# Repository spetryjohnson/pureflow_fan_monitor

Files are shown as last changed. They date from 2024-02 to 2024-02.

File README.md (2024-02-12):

# pureflow_fan_monitor

I have a couple of [PureFlow QT7 fanless fans](https://www.amazon.com/dp/B072PS3FR1?ref=ppx_yo2ov_dt_b_product_details&th=1) that I want to monitor and control through Home Assistant.

Specifically, I want Home Assistant to:

- Know if the fan is physically powered on or not
- Know the power level in use (0-9)
- Turn the fan on/off as part of automations 

I have solved this with a Raspberry Pi Zero W, a camera module, and an IR transmitter LED. 
 
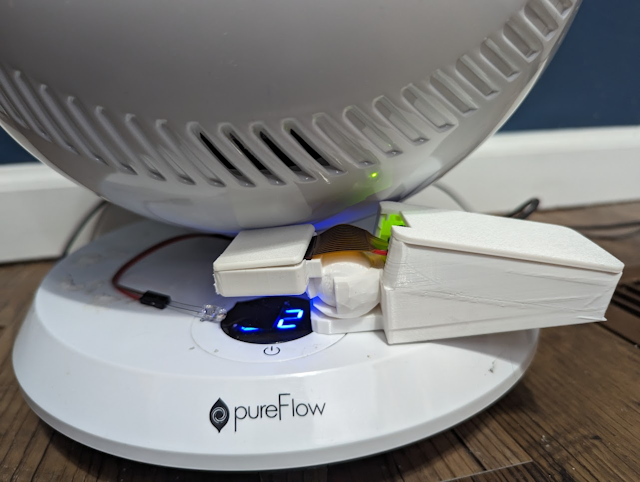
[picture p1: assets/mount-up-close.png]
Image of a PureFlow QT7 with my hackjob of a 3d printed case mounted to it


> [!WARNING]
> This works great for a Pi Zero W. The newer Pi Zero **2** W deprecates the legacy camera stack and requires a few changes to run. See the Pi Zero 2 section at the end of this page.

# Hardware setup

Required components:

- **Raspberry Pi Zero W** - the brains of the whole thing
- **Raspberry Pi camera** - for taking pictures of the fan's LCD
- **[IR LED](https://www.amazon.com/dp/B00M1PN5TK?psc=1&ref=ppx_yo2ov_dt_b_product_details)** - IR transmitter that sends commands to the fan
- **220 Ohm resistor** - limits LED current draw and protects the PI
- **BC-337 transistor** - allows LED to be switched on/off by a GPIO pin
- **3d printed enclosure** - (optional) for mounting to the base of the fan

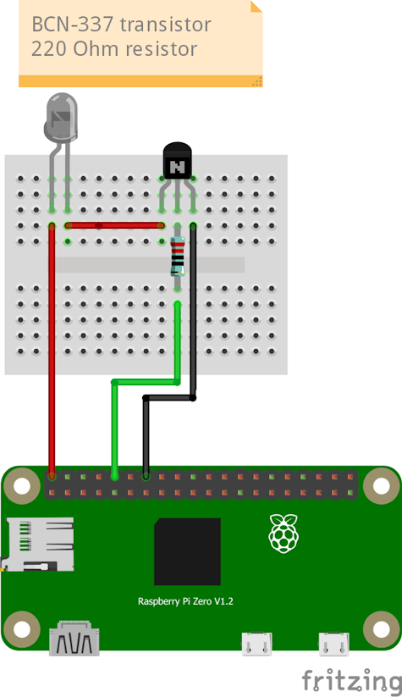
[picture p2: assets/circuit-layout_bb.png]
Fritzing image showing a circuit from 5V to LED to collector side of transistor, with resistor between base and GPIO 15


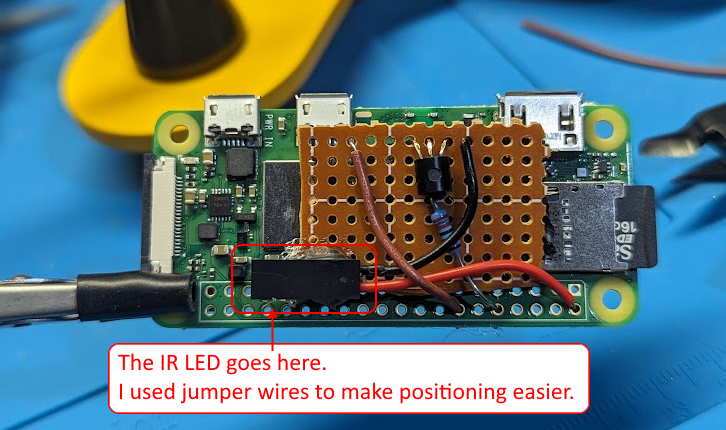
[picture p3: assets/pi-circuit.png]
Picture of the pi with the transistor and resitor soldered to it


> [!NOTE]
> Other transistors and resistors might work. I'm not a hardware guy, so follow my instructions at your own risk ;)

# Software installation

This system relies on two Python scripts that are installed as systemd services:

- **pureflow_OCR.service** - Monitors the fan's LCD screen and reports the current power level over MQTT
- **pureflow_webIR.service** - Web app that triggers IR transmissions in response to HTTP requests

## Get source code

Install the Github CLI and then pull down this repo (or use any other way to get these files onto your machine).

```
From https://github.com/cli/cli/blob/trunk/docs/install_linux.md

type -p curl >/dev/null || (sudo apt update && sudo apt install curl -y)
curl -fsSL https://cli.github.com/packages/githubcli-archive-keyring.gpg | sudo dd of=/usr/share/keyrings/githubcli-archive-keyring.gpg \
&& sudo chmod go+r /usr/share/keyrings/githubcli-archive-keyring.gpg \
&& echo "deb [arch=$(dpkg --print-architecture) signed-by=/usr/share/keyrings/githubcli-archive-keyring.gpg] https://cli.github.com/packages stable main" | sudo tee /etc/apt/sources.list.d/github-cli.list > /dev/null \
&& sudo apt update \
&& sudo apt install gh -y
```
```
gh repo clone spetryjohnson/pureflow_fan_monitor
```

## Create RAM disk for image manipulation (optional)

This involves a lot of reading and writing image files to disk. To reduce wear on the SD card, create a tmpfs RAM disk to hold them instead.

```
sudo mkdir /var/tempmem
sudo nano /etc/fstab

Add this line to fstab:
  -> tmpfs /var/tempmem tmpfs nodev,nosuid,size=400M 0 0

sudo mount -a
```

## Install ssocr

[ssocr](https://github.com/auerswal/ssocr) is a third party tool for doing OCR of "seven segment displays", e.g. the LCD that displays the power level.

```
sudo apt install ssocr -y
```

## Install ImageMagick

[ImageMagick](https://imagemagick.org/) is an open source image manipulation suite. It is required to run the Python module [Wand](https://pypi.org/project/Wand/)

```
sudo apt install imagemagick -y
```

## Install pigpio daemon

This is needed by the PiIR package for sending IR commands.

```
sudo apt install pigpio -y
sudo systemctl enable pigpiod
sudo systemctl start pigpiod
```

## Create virtual Python environment (optional) 

It's recommended to use a virtual environment, unless this is the only Python script running on the pi. Even then, it's good practice. (If you skip this step, you'll need to adjust paths in the service files accordingly)

```
python3 -m venv .venv
. .venv/bin/activate
```

## Install Python dependencies

```
pip install picamera Wand paho-mqtt Pillow flask gunicorn PiIR
```

- Camera, Wand, paho-mqtt, and Pillow are used for OCR
- Flask, gunicorn, and PiIR are used for the web app and IR control

## Create the system services

```
sudo cp displayOCR/pureflow_OCR.service /lib/systemd/system
sudo systemctl enable pureflow_OCR.service
sudo systemctl start pureflow_OCR.service

sudo cp webIR/pureflow_webIR.service /lib/systemd/system
sudo systemctl enable pureflow_webIR.service
sudo systemctl start pureflow_webIR.service
```

# Adding the monitor to the fan

> [!IMPORTANT]
> You will need to tweak the config file based on how you mount the camera to the fan.

## Placement

I place my monitors on the right hand side of the fans so that all of the cables can route behind the fan and be hidden from view.

You want the camera to be 90 degrees rotated with respect to the LCD display. Technically you should be able to use any orientation, since we rotate the image before processing it anyways, but in my testing I found *significant* performance degredation (at least on a pi zero w) when rotating by values other than exactly 90 degrees.

## Testing the camera

Access the web app at **http://<ip_or_host>:8080**. It will show you the current power reading, the image that last caused a *change* to the power reading, and the 10 most recent readings.

For each reading you'll see the raw image captured by the camera as well as the processed image that was used for OCR.  

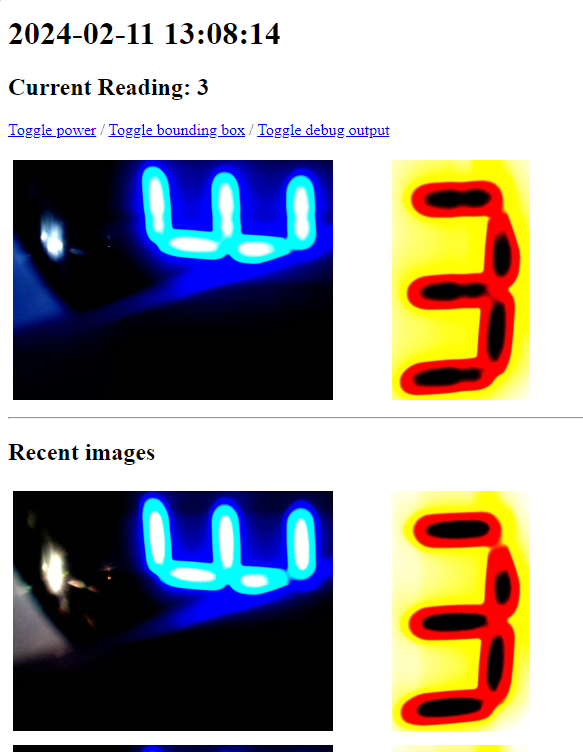
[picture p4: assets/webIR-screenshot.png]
Screenshot of the web app showing recent images and readings


> [!NOTE]
> If it isn't cropping the image correctly for your placement either adjust the camera so that it is, or adjust the cropping region defined in `config.ini`.

## Adjusting the cropped region

> [!NOTE]
> The fan supports speeds up to 12, but I only go up to 4 or 5. I designed this app to read the rightmost digit only.

In the web app, click the "toggle bounding box" link. This will begin adding a red box over the images showing the region that is being cropped and processed.

Load one of those images into an image editor and determine the X,Y coordinates that cleanly isolate the rightmost digit of the LCD display. 

Put those coordinates into `config.ini`

```
X,Y of top-left start and bottom-right end of the cropping region

CROP_STARTX = 250	
CROP_STARTY = 0 	
CROP_ENDX = 640
CROP_ENDY = 222
```

> [!IMPORTANT]
> Don't forget to disable the bounding box once you get it working, it adds unnecessary load.

# Setting up Home Assistant

The monitor will post power level changes to Home Assistant via MQTT. 

Home Assistant will use a Template Switch to monitor the state and to trigger IR commands to the fan when the switch is toggled.

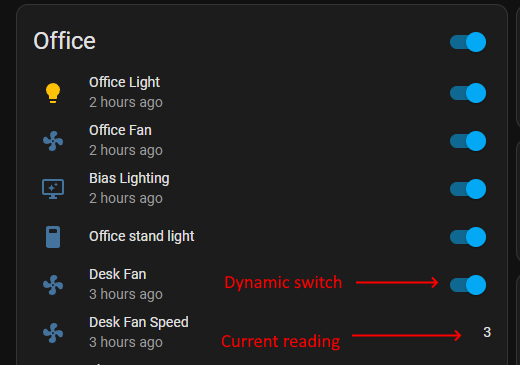
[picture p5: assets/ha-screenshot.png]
Screenshot of Home Assistant showing a template switch and the current power level in a dashboard


## MQTT setup

Edit `config.ini` and include your MQTT broker information.

```
SEND_MQTT = True
MQTT_HOST = your.mqtt.host
MQTT_TOPIC = home/rooms/office/deskfan/power
```

## MQTT sensor 

In Home Assistant, edit `configuration.yaml` and define a new sensor:

```
mqtt:
  sensor:
    - name: "Pureflow Fan Power Level"
      unique_id: "sensor_office_deskfan_power"
      state_topic: "home/rooms/office/deskfan/power"
      value_template: "{{ value_json.currentState }}"
      payload_available: "online"
      payload_not_available: "offline"
      json_attributes_topic: "home/rooms/office/deskfan"
      json_attributes_template: "{{ value_json | tojson }}"
```

## MQTT REST command

In Home Assistant, edit `configuration.yaml` and define a new REST command. This allows HA to make HTTP calls to the web service.

```
rest_command:
  pureflow_fan_toggle_power:
    url: "http://<ip_or_hostname_of_pi>:8080/toggle"
    method: GET
```

## Template switch

A Template Switch in Home Assistant will act as a power button. It uses the current power level to determine if the fan is "on" or "off" and calls the appropriate service to switch states.

```
switch:
  - platform: template
    switches:
      pureflow_fan_dynamic_switch:
        unique_id: "pureflow_fan_dynamic_switch"
        friendly_name: "Pureflow Fan Dynamic Switch"
        value_template: "{{ not states('sensor.pureflow_fan_power_level') in ['off', '0'] }}"
        turn_on:
          - condition: state
            entity_id: switch.pureflow_fan_dynamic_switch
            state: 'off'
          - service: rest_command.pureflow_fan_toggle_power
        turn_off:
          - condition: state
            entity_id: switch.pureflow_fan_dynamic_switch
            state: 'on'
          - service: rest_command.pureflow_fan_toggle_power
```

# Troubleshooting

## Manually sending the power toggle IR command

`piir play --gpio 15 --file webIR/pureflow-IR-commands.json power`

## Checking the logs of a running service

`sudo journalctl -f -u pureflow_OCR.service`

## Running the web server manually for testing

`flask run --host=0.0.0.0 --port 8080 --debug`

# Pi Zero 2 W support

There are major changes to the camera stack with the 2nd iteration of the Pi Zero. You will need to:

1. Disable the legacy camera support in `raspi-config`
1. Install [PiCamera2](https://github.com/raspberrypi/picamera2)
1. Create your Python virtual environment using `--system-site-packages` ([see this link](https://forums.raspberrypi.com/viewtopic.php?t=361758))

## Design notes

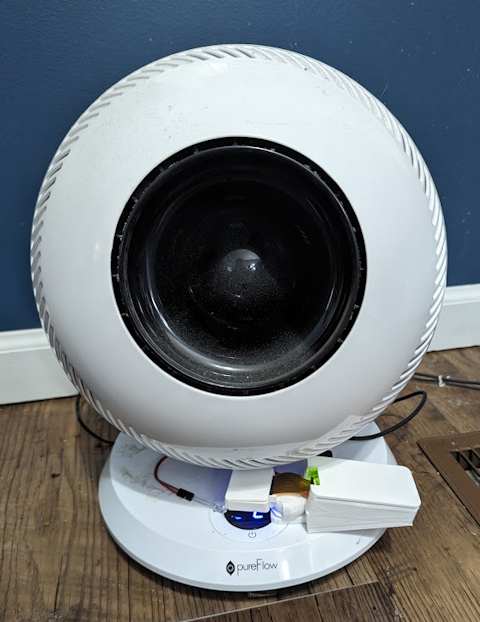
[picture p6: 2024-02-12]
assets/pureflow_fan.png

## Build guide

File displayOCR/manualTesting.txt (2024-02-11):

# take a picture with same settings used by the app
raspistill -w 640 -h 480 -n -co 85 -t 2000 -o test.jpg

# crop using imagemagick (equivalent to Wand in python)
# specific dimensions will need determined after camera is fixed in place
# format is ({length_of_cropped_area}x{height_of_cropped_area}+{xstart}+{ystart}
convert test.jpg -crop 393x222+180+0 test_cropped.jpg

# rotate
convert test_cropped.jpg -rotate 90 test_rotated.jpg

# negation makes ssocr more accurate
convert test_rotated.jpg -negate test_negated.jpg

# OCR
ssocr -d 1 test_negated.jpg

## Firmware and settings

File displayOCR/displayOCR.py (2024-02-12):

import os, sys, datetime, time, io 

# For handling the config file
from configparser import ConfigParser, ExtendedInterpolation

# For image generation and preparation
from shutil import copyfile
from picamera import PiCamera
from wand.image import Image
from PIL import Image as PilImage, ImageDraw as PilImageDraw

# For shelling out to ssocr
import subprocess

# For MQTT
import paho.mqtt.client as mqtt
import json

# For RCP communication
import _thread
from multiprocessing.connection import Listener
from multiprocessing import ProcessError as MultiprocProcessError

#--------------------------------------------------------
# Load config file
#
# (See config file for setting documentation)
#
# Some of these can be changed at runtime through RPC calls, others
# cannot. For simplicity everything is a mutable global.
#--------------------------------------------------------
config = ConfigParser(interpolation=ExtendedInterpolation())
config.read('../config.ini')

if (os.path.exists('../config.ini.local')):
	config.read('../config.ini.local')

CROP_STARTX = config['OCR'].getint('CROP_STARTX')
CROP_STARTY = config['OCR'].getint('CROP_STARTY')
CROP_ENDX = config['OCR'].getint('CROP_ENDX')
CROP_ENDY = config['OCR'].getint('CROP_ENDY')
SEND_MQTT = config['OCR'].getboolean('SEND_MQTT')
MQTT_HOST = config['OCR'].get('MQTT_HOST')
MQTT_TOPIC = config['OCR'].get('MQTT_TOPIC')
MAX_TIME_BETWEEN_MQTT_LOG_SEC = config['OCR'].getint('MAX_TIME_BETWEEN_MQTT_LOG_SEC')
ADD_CROP_BOX_TO_IMG = config['OCR'].getboolean('ADD_CROP_BOX_TO_IMG')
DEBUG = config['OCR'].getboolean('DEBUG')
STATIC_FILE_PATH = config['OCR'].get('STATIC_FILE_PATH')
LAST_CHANGE_ORIG_PATH = config['OCR'].get('LAST_CHANGE_ORIG_PATH')
LAST_CHANGE_PROC_PATH = config['OCR'].get('LAST_CHANGE_PROC_PATH')
LAST_CHANGE_TEXT_PATH = config['OCR'].get('LAST_CHANGE_TEXT_PATH')
LAST_ERROR_PATH = config['OCR'].get('LAST_ERROR_PATH')
MAX_IMAGES_TO_KEEP = config['OCR'].getint('MAX_IMAGES_TO_KEEP')
LOOP_DELAY_SEC = config['OCR'].getfloat('LOOP_DELAY_SEC')
USE_RPC = config['OCR'].getboolean('USE_RPC')
RPC_PORT = config['OCR'].getint('RPC_PORT')
RPC_SECRET = bytes(config['OCR'].get('RPC_SECRET', 'Super secret'), 'utf-8')

#--------------------------------------------------------
# Use a background thread to listen to commands from the web app 
#--------------------------------------------------------
def startListenerThread():
	global DEBUG, ADD_CROP_BOX_TO_IMG
	
	address = ('localhost', RPC_PORT)
	listener = Listener(address, authkey=RPC_SECRET)

	while True:
		if (DEBUG): print('[listener] Waiting for connection...')
		try:
			conn = listener.accept()
		except MultiprocProcessError:
			print('[listener] Error making connection. Could be invalid secret key from client')
			continue
		
		if (DEBUG): print ('[listener] Connection accepted from ', listener.last_accepted)

		if (DEBUG): print ('[listener] Waiting for message...')
		msg = conn.recv()
		if (DEBUG): print ('[listener] Received: ', msg)
		
		# Ugh I'm on python 3.9 which doesn't have switch case. 
		# What is this the 1700s?
		if (msg == 'toggleBoundingBox'):
			ADD_CROP_BOX_TO_IMG = not ADD_CROP_BOX_TO_IMG
		elif (msg == 'toggleDebug'):
			DEBUG = not DEBUG
		else:
			print('[listener] Unrecognized command: ', msg)
			
		if (DEBUG): print('[listener] Closing connection')
		conn.close()
	
	if (DEBUG): print('[listener] Closing listener')
	listener.close()

#--------------------------------------------------------
# Main program
#--------------------------------------------------------
if __name__ == '__main__':
	# local vars
	if (SEND_MQTT):
		mqttClient = mqtt.Client()
	
	imageCounter = 0			# For rotating image names
	valueOfLastChange = ''		# Value that last triggered a change in value
	timeOfLastChange = datetime.datetime.now()

	if (USE_RPC):
		print('Start background listener... ', end='', flush=True)
		_thread.start_new(startListenerThread, ())	
		print('Done!')

	print('Init camera....', end='', flush=True)
	with PiCamera() as camera:
		camera.resolution  = (640, 480)
		camera.contrast = 85
		time.sleep(2)
		print(' Ready!')

		# For each image we store the original image, the processed image,
		# and the OCR reading.

		while(True):
			now = datetime.datetime.now()	
			
			if (imageCounter >= MAX_IMAGES_TO_KEEP):
				imageCounter = 1
			else:
				imageCounter = imageCounter + 1

			pathPrefix = STATIC_FILE_PATH + 'reading-' + str(imageCounter)

			origImagePath = pathPrefix + '-orig.jpg'
			procImagePath = pathPrefix + '-processed.jpg'
			textReadingPath = pathPrefix + '-reading.txt'
			
			if (DEBUG): print('Getting image ' + origImagePath + '...', end='', flush=True)
			camera.capture(origImagePath)
			if (DEBUG): print('Done!')
			
			if (ADD_CROP_BOX_TO_IMG):
				if (DEBUG): print('Adding bounding box to ' + origImagePath + '... ', end='', flush=True)
				origImg = PilImage.open(origImagePath)
				draw = PilImageDraw.Draw(origImg)
				draw.rectangle((CROP_STARTX, CROP_STARTY, CROP_ENDX, CROP_ENDY), fill = None, outline="red")
				origImg.save(origImagePath, "JPEG")
				if (DEBUG): print('Done!')
			
			if (DEBUG): print('Processing image ' + procImagePath + '... ', end='', flush=True)
			with Image(filename = origImagePath) as image:
				with image.clone() as clone:
					clone.crop(CROP_STARTX, CROP_STARTY, CROP_ENDX, CROP_ENDY)
					clone.rotate(-90, 'black')
					clone.negate(False, None)
					clone.save(filename = procImagePath)
			if (DEBUG): print('Done!')
			
			try:
				if (DEBUG): print('Doing OCR on ' + procImagePath + '... ', end='', flush=True)
				
				try:
					newReading = subprocess \
					.check_output(['ssocr', '-d', '1', procImagePath], stderr=subprocess.PIPE) \
					.decode(sys.stdout.encoding) \
					.strip()
				except subprocess.CalledProcessError as e:
					# don't need to output error, message already sent to stderr/stdout
					# logging it can be useful though
					message = e.stderr.decode()
					if (DEBUG): print('ERROR: ' + message)
					
					f = open(LAST_ERROR_PATH, 'w')
					f.write(message)
					f.close()
					
					newReading = "off"
				
				# Special handling for known issues
				if (newReading == 'y'): newReading = '4'
				elif (newReading == 'e'): newReading = 'off'
				
				# Write reading to disk
				f = open(textReadingPath, 'w')
				f.write(newReading)
				f.close()
				
				if (DEBUG): print('(' + newReading + ') Done!')
				
				valueChanged = (newReading != valueOfLastChange)
				secondsSinceChange = abs(now - timeOfLastChange).seconds
				timeToReport = (secondsSinceChange > MAX_TIME_BETWEEN_MQTT_LOG_SEC)

				# If a change occurred then update the files that capture the last change trigger
				if (valueChanged):
					if (DEBUG): print('Value changed, updating "last update" files...')
					valueOfLastChange = newReading
					timeOfLastChange = now
					copyfile(origImagePath, LAST_CHANGE_ORIG_PATH)
					copyfile(procImagePath, LAST_CHANGE_PROC_PATH)
					copyfile(textReadingPath, LAST_CHANGE_TEXT_PATH)
					print(newReading + ' [NEW]')
				elif (timeToReport):
					print(newReading + ' [' + str(secondsSinceChange) + ' seconds since last report]')

				# Notify MQTT
				if (SEND_MQTT and (valueChanged or timeToReport)):
					if (DEBUG): print('Sending MQTT update...', end='', flush=True)

					jsonData = json.dumps({ \
						"currentState": newReading, \
						"changedOn": now \
					}, default = str)

					mqttClient.connect(MQTT_HOST)	
					mqttClient.publish(MQTT_TOPIC, jsonData, retain=True)
					mqttClient.disconnect()	
					timeOfLastChange = now
					if (DEBUG): print('Done!')
				
				if (LOOP_DELAY_SEC > 0):
					time.sleep(LOOP_DELAY_SEC)
				
			# mqtt connection exception - slight delay then continue
			except Exception as e: 
				print('ERROR: ', e)
				time.sleep(3)
		

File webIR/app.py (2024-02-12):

import datetime, os, glob
from flask import Flask, render_template
from piir import Remote
from pathlib import Path

# For handling the config file
from configparser import ConfigParser, ExtendedInterpolation

# For RPC to the OCR app
from multiprocessing.connection import Client

# For getting current hostname
import socket

#--------------------------------------------------------
# Load config file
#
# (See config file for setting documentation)
#
# Some of these can be changed at runtime through RPC calls, others
# cannot. For simplicity everything is a mutable global.
#--------------------------------------------------------
config = ConfigParser(interpolation=ExtendedInterpolation())
config.read('../config.ini')
STATIC_FILE_PATH = config['Web'].get('STATIC_FILE_PATH')
LAST_CHANGE_TEXT_PATH = config['Web'].get('LAST_CHANGE_TEXT_PATH')
USE_RPC = config['Web'].getboolean('USE_RPC')
RPC_PORT = config['Web'].getint('RPC_PORT')
RPC_SECRET = bytes(config['Web'].get('RPC_SECRET', 'Super secret'), 'utf-8')
IR_LED_GPIO = config['Web'].getint('IR_LED_GPIO')

# Local settings (not in config)
AUTO_RERESH_SECONDS = 0

#--------------------------------------------------------
# Flash web app
#-----------------------------
app = Flask(__name__, 
	static_url_path='/static/', 
	static_folder=STATIC_FILE_PATH)

@app.route('/')
def index():
	now = datetime.datetime.now().strftime('%Y-%m-%d %H:%M:%S')
	hostname = socket.gethostname()

	# Show current reading
	currentReading = '';
	if (os.path.exists(LAST_CHANGE_TEXT_PATH)):
		with open(LAST_CHANGE_TEXT_PATH) as filetext:
			for line in filetext:
				currentReading = currentReading + line

	# Show list of images, most recent first
	origImages = glob.glob(STATIC_FILE_PATH + '*-orig.jpg')
	origImages.sort(key=os.path.getmtime, reverse=True)
	origImageNames = [os.path.basename(x) for x in origImages]
	
	return render_template(
		'index.html', 
		hostname=hostname,
		now=now, 
		autoRefreshSec=AUTO_RERESH_SECONDS, 
		currentReading=currentReading, 
		origImageNames=origImageNames)

@app.route('/toggle')
def toggle():
	remote = Remote('pureflow-IR-commands.json', IR_LED_GPIO)
	remote.send('power')
	return render_template('toggle.html')

@app.route('/toggleBoundingBox')
def toggleBoundingBox():
	if (not USE_RPC):
		abort(409)
	
	address = ('localhost', RPC_PORT)
	conn = Client(address, authkey=RPC_SECRET)
	conn.send('toggleBoundingBox')
	conn.close()
	return ('Success', 200)

@app.route('/toggleDebug')
def toggleDebug():
	if (not USE_RPC):
		abort(409)
	
	address = ('localhost', RPC_PORT)
	conn = Client(address, authkey=RPC_SECRET)
	conn.send('toggleDebug')
	conn.close()
	return ('Success', 200)


@app.route('/toggleAutoRefresh')
def toggleAutoRefresh():
	global AUTO_RERESH_SECONDS

	if (AUTO_RERESH_SECONDS == 0):
		AUTO_RERESH_SECONDS = 1
	else:
		AUTO_RERESH_SECONDS = 0

	return ('Success', 200)

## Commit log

2024-02-11 Big updates to the docs, fixed typos in service files
    [circuit-layout.fzz]
2024-02-12 Added local config override, error handling, auto refresh
    [app.py, displayOCR.py]
2024-02-12 Fixed issue w/ MQTT timeout tracking
    [displayOCR.py]
2024-02-12 Updated image of circuit
